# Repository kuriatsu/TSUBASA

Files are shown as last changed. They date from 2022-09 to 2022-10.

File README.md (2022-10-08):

# TSUBASA

tsubasa
tsubasa
tsubasa

## Features
* Row staggered split keyboard
* Hotswap
* Multi function rotary encoder (scroll, pgup/down, volume, screen brightness etc)
* LCD indicator for the rotary encoder
* Handwire

## BUILD
Build guide is [here!](build_guide.md)

## Firmware
[QMK Firmware]() Now in PR...

The basic keymap is avairable at  
qmk_firmware/keyboards/handwired/tsubasa

If you want to use custom keymap with multifunctional rotary encoder, use keymap/multifunc_encoder

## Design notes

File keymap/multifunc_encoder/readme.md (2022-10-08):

# Keymap for tsubasa with multifunctional rotary encoder
keymap

## Setup
Move this file to qmk_firmware
```bash
cp -r multifunc_encoder qmk_firmware/keyboards/handwired/tsubasa/keymaps
```

## Build and Flash
```bash
qmk compile -kb handwired/tsubasa -km default
```

Flashing example for this keyboard:

```bash
qmk flash -kb handwired/tsubasa -km default
```

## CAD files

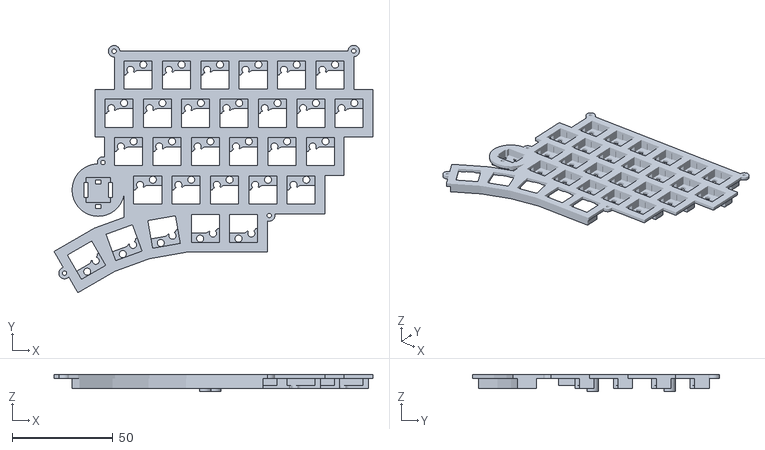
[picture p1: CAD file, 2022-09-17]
stl/right_plate.stl
158.0 x 122.6 x 8.60

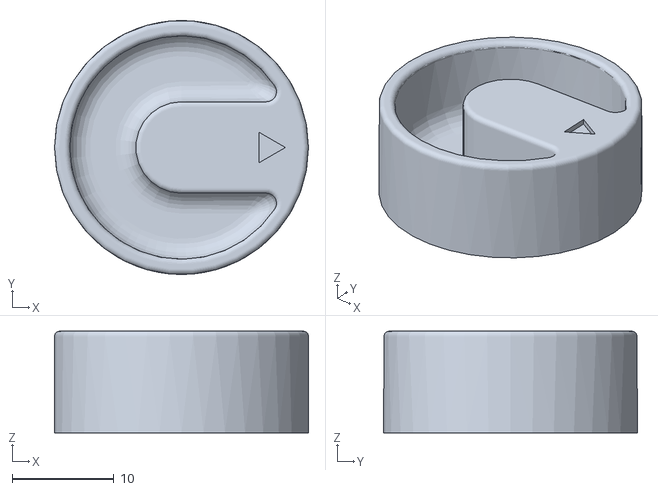
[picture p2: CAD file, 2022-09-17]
stl/rotary_encoder.stl
25.0 x 25.0 x 10.0

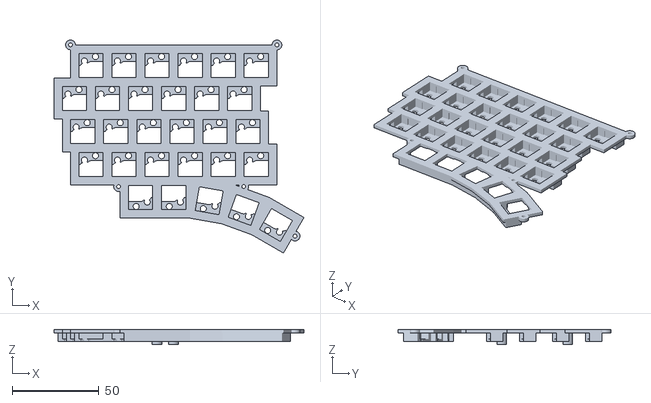
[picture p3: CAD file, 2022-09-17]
stl/left_plate.stl
143.7 x 122.5 x 8.60

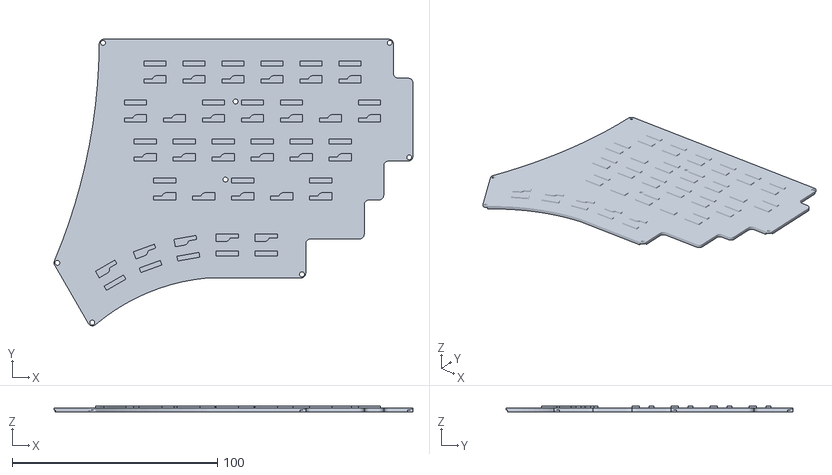
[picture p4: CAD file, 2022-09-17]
stl/right_bottom_cover.stl
174.9 x 139.7 x 3.00

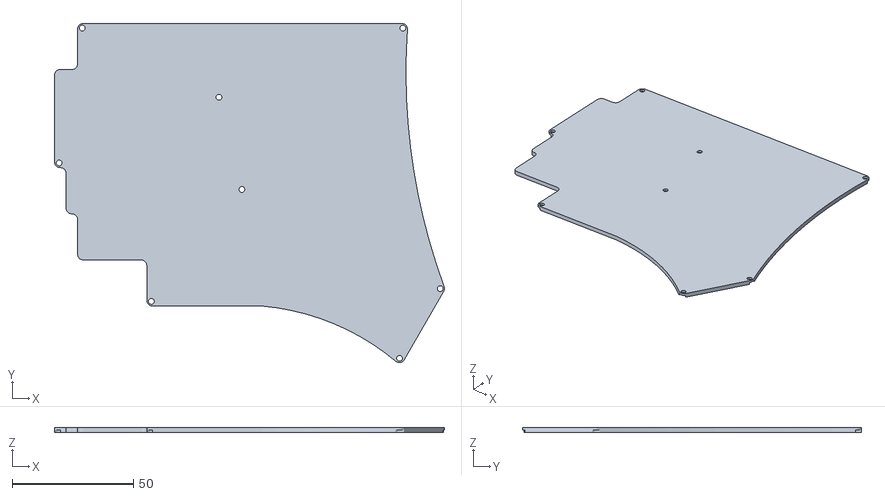
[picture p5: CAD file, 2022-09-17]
stl/left_bottom_cover.stl
160.6 x 139.7 x 2.00

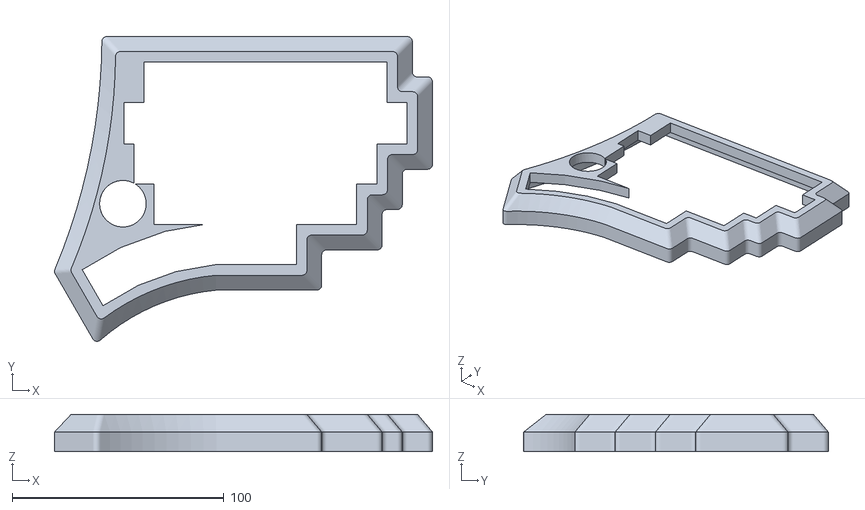
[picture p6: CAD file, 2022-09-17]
stl/right_body.stl
178.3 x 143.8 x 17.5

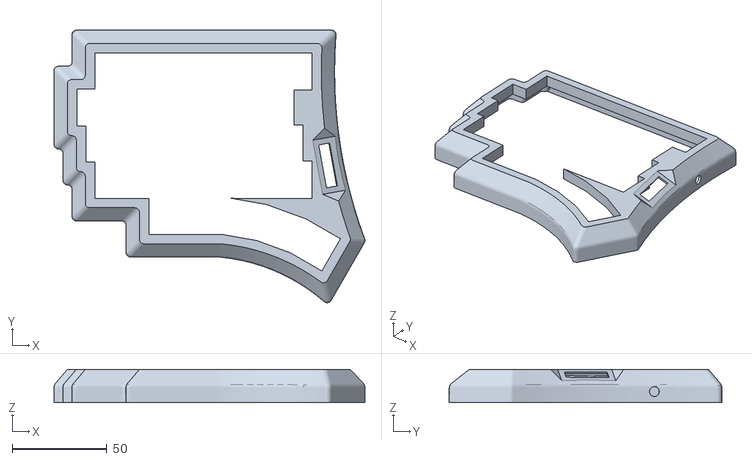
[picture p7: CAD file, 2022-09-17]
stl/left_body.stl
163.9 x 143.7 x 17.5

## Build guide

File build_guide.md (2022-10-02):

### Requirement
|Name|Quantity|Description|
|:--|:-:|:--|
|Keycap| | what you want |
|Switch|59| cherry, 5pin or 3pin|
|pro micro | 2 | |
|Hotswap socket| 59 | [Kailh Switch Socket](https://ja.aliexpress.com/item/4001051840976.html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,scm-url:1007.40050.281175.0,pvid:c32d0aa9-fbd5-4a4a-93a9-2d2d8cc6ecd6,tpp_buckets:668%232846%238114%231999&pdp_ext_f=%7B%22sku_id%22%3A%2210000013817160772%22%2C%22sceneId%22%3A%2230050%22%7D&pdp_npi=2%40dis%21JPY%211123.0%211123.0%21%21%21%21%21%40210323b516634190543258981ee252%2110000013817160772%21rec)|
|LCD| 1 | 128x36 SSD1306|
|Rotary Encoder| 1 |ec11 base geometry 12.5x12.5x4.5|
|TypeC fimale socket | 1 | [Link](https://ja.aliexpress.com/item/1005001417328558.html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,scm-url:1007.40050.281175.0,pvid:e25c7a58-81fe-40ad-9aa8-c0a3f16b51aa,tpp_buckets:668%232846%238114%231999&pdp_ext_f=%7B%22sku_id%22%3A%2212000017755357302%22%2C%22sceneId%22%3A%2230050%22%7D&pdp_npi=2%40dis%21JPY%21104.0%21104.0%21%21%21%21%21%40210323b516634188029416631ee252%2112000017755357302%21rec)|
|trrs fimale socket | 1 | [Link](https://ja.aliexpress.com/item/33029465106.html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,scm-url:1007.40050.281175.0,pvid:950b87d2-5227-404c-8bc5-f2671595dc42,tpp_buckets:668%232846%238114%231999&pdp_ext_f=%7B%22sku_id%22%3A%2267273462020%22%2C%22sceneId%22%3A%2230050%22%7D&pdp_npi=2%40dis%21JPY%21118.0%21118.0%21%21%21%21%21%40210323b516634189735138200ee252%2167273462020%21rec) |
|Insert nut| 24 | m2 3mm |
|Skrew| 24 | m2 4mm |
|Diode| 59 | 1N4148 |
|Enameled copper wire | | 0.2mm-1.0mm |
|WS2812| 6 | (optional)|
|TRRS cable | 1 | |

### Procedure
1. Print parts (shell, middle plate, bottom plate, rotary encoder)

2. Insert nut with soldering iron



3. Attach switches, socket, rotary encoder on the middle plate

4. Solder the sockets, LCD, rotary encoder, TRRS socket, and type-c socket   
   <p>
      
      
   </p>
     
6. Attach LCD, TRRS socket, and type-c socket to the shell




7. Put LED backlight (anywhere you want)


8. Screw them and DONE!


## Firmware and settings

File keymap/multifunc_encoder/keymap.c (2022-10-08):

/* Copyright 2021 kuriatsu
 *
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
 * You should have received a copy of the GNU General Public License
 * along with this program.  If not, see <http://www.gnu.org/licenses/>.
 */
#include QMK_KEYBOARD_H

// Defines names for use in layer keycodes and the keymap
enum layer_names {
    _BASE,
    _ENC_WH,
    _ENC_VOL,
    _ENC_BRI,
    _FN
};

// Defines the keycodes used by our macros in process_record_user
enum custom_keycodes {
    ENC_CNG = SAFE_RANGE
};

const uint16_t PROGMEM keymaps[][MATRIX_ROWS][MATRIX_COLS] = {
    [_BASE] = LAYOUT(
         KC_1,    KC_2,    KC_3,    KC_4,    KC_5,    KC_6,                          KC_7,    KC_8,    KC_9,    KC_0, KC_MINS,  KC_EQL,
       KC_TAB,    KC_Q,    KC_W,    KC_E,    KC_R,    KC_T,                          KC_Y,    KC_U,    KC_I,    KC_O,    KC_P, KC_LBRC, KC_RBRC,
      KC_LCTL,    KC_A,    KC_S,    KC_D,    KC_F,    KC_G,                          KC_H,    KC_J,    KC_K,    KC_L, KC_SCLN, KC_QUOT,
      KC_LSFT,    KC_Z,    KC_X,    KC_C,    KC_V,    KC_B,              ENC_CNG,    KC_N,    KC_M, KC_COMM,  KC_DOT, KC_SLSH,
                         KC_ESC, KC_RGUI, KC_LALT,  KC_SPC, KC_LSFT,     KC_BSPC,  KC_ENT, MO(_FN), KC_BSLS,  KC_GRV
    ),
    [_ENC_WH] = LAYOUT(
      _______, _______, _______, _______, _______, _______,                       _______, _______, _______, _______, _______, _______,
      _______, _______, _______, _______, _______, _______,                       _______, _______, _______, _______, _______, _______, _______,
      _______, _______, _______, _______, _______, _______,                       _______, _______, _______, _______, _______, _______,
      _______, _______, _______, _______, _______, _______,              _______, _______, _______, _______, _______, _______,
      _______, _______, _______, _______, _______,                       _______, _______, _______, _______, _______
    ),
    [_ENC_VOL] = LAYOUT(
      _______, _______, _______, _______, _______, _______,                       _______, _______, _______, _______, _______, _______,
      _______, _______, _______, _______, _______, _______,                       _______, _______, _______, _______, _______, _______, _______,
      _______, _______, _______, _______, _______, _______,                       _______, _______, _______, _______, _______, _______,
      _______, _______, _______, _______, _______, _______,              _______, _______, _______, _______, _______, _______,
      _______, _______, _______, _______, _______,                       _______, _______, _______, _______, _______
    ),
    [_ENC_BRI] = LAYOUT(
      _______, _______, _______, _______, _______, _______,                       _______, _______, _______, _______, _______, _______,
      _______, _______, _______, _______, _______, _______,                       _______, _______, _______, _______, _______, _______, _______,
      _______, _______, _______, _______, _______, _______,                       _______, _______, _______, _______, _______, _______,
      _______, _______, _______, _______, _______, _______,              _______, _______, _______, _______, _______, _______,
      _______, _______, _______, _______, _______,                       _______, _______, _______, _______, _______
    ),
    [_FN] = LAYOUT(
        KC_F1,   KC_F2,   KC_F3,   KC_F4,   KC_F5,   KC_F6,                         KC_F7,   KC_F8,   KC_F9,  KC_F10,  KC_F11,  KC_F12,
      _______, XXXXXXX, KC_BTN1, KC_MS_U, KC_BTN2, RGB_TOG,                       XXXXXXX, XXXXXXX, XXXXXXX, XXXXXXX, KC_PSCR, XXXXXXX, XXXXXXX,
      _______, XXXXXXX, KC_MS_L, KC_MS_D, KC_MS_R, RGB_MOD,                       KC_LEFT, KC_DOWN,   KC_UP, KC_RGHT, XXXXXXX, XXXXXXX,
      _______, XXXXXXX, XXXXXXX, XXXXXXX, RGB_VAI, RGB_HUI,              _______, XXXXXXX, XXXXXXX, XXXXXXX, XXXXXXX, XXXXXXX,
      _______, _______, _______, _______, _______,                       _______, _______, _______, _______, _______
    )
};


#ifdef ENCODER_MAP_ENABLE
const uint16_t PROGMEM encoder_map[][NUM_ENCODERS][2] = {
    [_BASE]    = { ENCODER_CCW_CW(KC_PGUP, KC_PGDN) },
    [_ENC_WH]  = { ENCODER_CCW_CW(KC_WH_U, KC_WH_D) },
    [_ENC_VOL] = { ENCODER_CCW_CW(KC_VOLU, KC_VOLD) },
    [_ENC_BRI] = { ENCODER_CCW_CW(KC_BRIU, KC_BRID) },
    [_FN]      = { ENCODER_CCW_CW(_______, _______) }
};
#endif

uint8_t mod_state;
bool process_record_user(uint16_t keycode, keyrecord_t *record) {
    mod_state = get_mods();
    switch (keycode) {
	case KC_BSPC:
	{
            static bool delkey_registered;
            if (record->event.pressed) {
                if (mod_state & MOD_MASK_SHIFT) {
                    del_mods(MOD_MASK_SHIFT);
                    register_code(KC_DEL);
                    delkey_registered = true;
                    set_mods(mod_state);
                    return false;
                }
            } else {
                if (delkey_registered) {
                    unregister_code(KC_DEL);
                    delkey_registered = false;
                    return false;
                }
            }
            return true;
        }
	case ENC_CNG:
	{
	    if (record->event.pressed) {
		switch (get_highest_layer(layer_state)) {
		    case _BASE:
			if (mod_state & MOD_MASK_SHIFT) {
			    layer_on(_ENC_BRI);
			} else {
			    layer_on(_ENC_WH);
			}
			break;
		    
		    case _ENC_WH:
			layer_off(_ENC_WH);
			if (mod_state & MOD_MASK_SHIFT) {

			} else {
			    layer_on(_ENC_VOL);
			}
			break;

		    case _ENC_VOL:
			layer_off(_ENC_VOL);
			if (mod_state & MOD_MASK_SHIFT) {
			    layer_on(_ENC_WH);
			} else {
			    layer_on(_ENC_BRI);
			}
			break;

		    case _ENC_BRI:
			layer_off(_ENC_BRI);
			if (mod_state & MOD_MASK_SHIFT) {
			    layer_on(_ENC_VOL);
			} else {
				
			}
			break;
		}
	    }
	    return true;
	}
    }
    return true;
}


#ifdef OLED_ENABLE
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

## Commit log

2022-02-26 add v1 project
    [rotaly_encoder.FCStd, rotaly_encoder.stl, socket_cover-5u.stl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]
2022-09-17 update stl
    [left_body.stl, left_bottom_cover.stl, left_plate.stl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]

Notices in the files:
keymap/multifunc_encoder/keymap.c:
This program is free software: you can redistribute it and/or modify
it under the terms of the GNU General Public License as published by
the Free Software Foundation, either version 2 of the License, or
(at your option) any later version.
